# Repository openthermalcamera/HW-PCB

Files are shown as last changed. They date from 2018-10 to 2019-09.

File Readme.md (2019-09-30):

# Open Thermal Camera - KiCad PCB
This repository contains KiCad source files for Open Thermal Camera PCB.

The PCB is 2 layer, thickness of 0.8mm (To accommodate the edge TypeC / MicroUSB connector)

Under releases you can find:
- Interactive BOM (.html)
- KiCost BOM (.xlsx)
- Gerbers
- Position files (.pos & .rpt)  

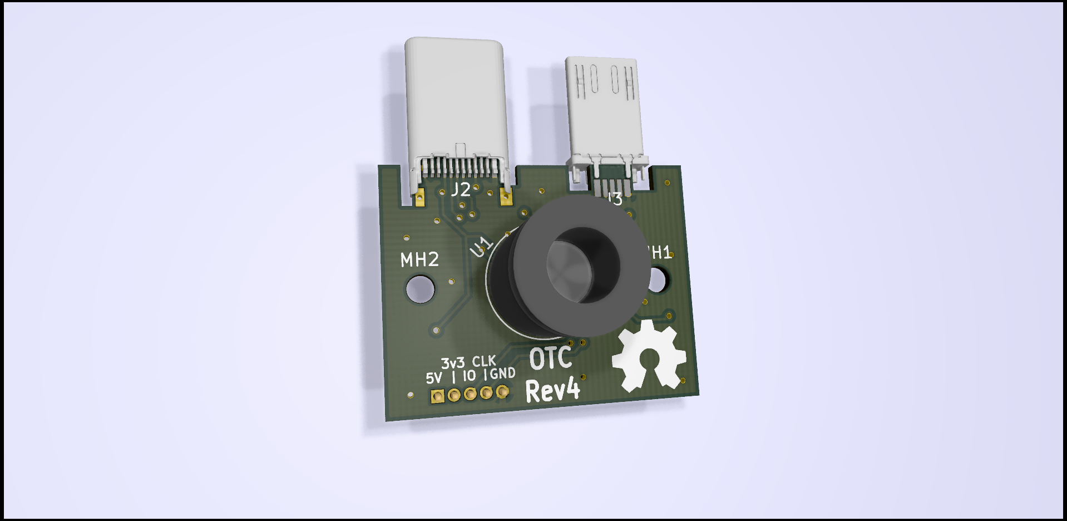
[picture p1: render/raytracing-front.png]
Raytracing render of rev4-fix1 PCB


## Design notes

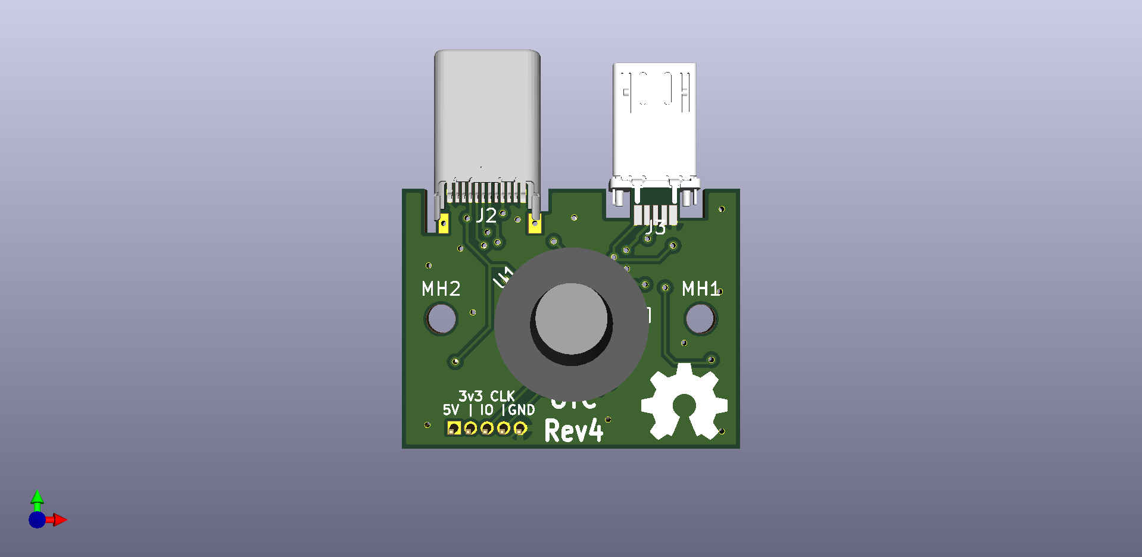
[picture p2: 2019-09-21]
render/render-front.png

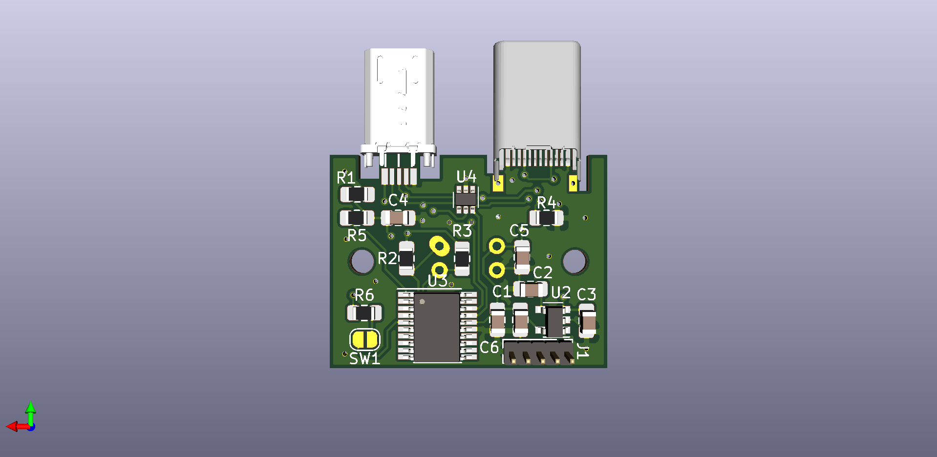
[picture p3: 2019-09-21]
render/render-back.png

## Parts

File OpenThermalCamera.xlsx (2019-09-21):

Prj: | OpenThermalCamera |  |  |  |  | Board Qty: | 1
Co.: | Martin Peterlin - TheMarpe |  |  |  |  | Unit Cost: | €45.13
Prj date: | 09/21/19 20:50:41 |  |  |  |  | Total Cost: | €45.13 |  |  |  | €47.81 | 13 of 13 parts found |  |  |  | €4.24 | 9 of 13 parts found |  |  |  | €46.12 | 13 of 13 parts found |  |  |  | €3.76 | 11 of 13 parts found |  |  |  | €311.62 | 7 of 13 parts found
$ date: | 2019-09-21 20:50:54
Global Part Info |  |  |  |  |  |  |  | Digi-Key |  |  |  |  | Farnell |  |  |  |  | Mouser |  |  |  |  | Newark |  |  |  |  | Rs Components
Refs | Value | Footprint | Manf | Manf# | Qty | Unit$ | Ext$ | Avail | Purch | Unit$ | Ext$ | Cat# | Avail | Purch | Unit$ | Ext$ | Cat# | Avail | Purch | Unit$ | Ext$ | Cat# | Avail | Purch | Unit$ | Ext$ | Cat# | Avail | Purch | Unit$ | Ext$ | Cat#
C1 | 2u2 | Capacitor_SMD:C_0805_2012Metric_Pad1.15x1.40mm_HandSolder |  | VJ0805G225KXYTW1BC | 1 | €0.16 | €0.16 | 3000 |  | €0.45 | €0.45 | 720-1727-1-ND (https://octopart.com/click/track?ai=8078&sig=0fba5b8&sid=459&ppid=46604723&vpid=464290379&ct=offers) | 11770 |  | €0.18 | €0.18 | 2896530 (https://octopart.com/click/track?ai=8078&sig=07624a5&sid=11744&ppid=46604723&vpid=494461261&ct=offers) | 1044 |  | €0.16 | €0.16 | 77VJ0805G225KXYTBC (https://octopart.com/click/track?ai=8078&sig=0643838&sid=2401&ppid=46604723&vpid=116520910&ct=offers) | 11770 |  | €0.16 | €0.16 | 62AC8496 (https://octopart.com/click/track?ai=8078&sig=0bba5bf&sid=2402&ppid=46604723&vpid=494777176&ct=offers)
C2 | 10n | Capacitor_SMD:C_0805_2012Metric_Pad1.15x1.40mm_HandSolder |  | 885012207011 | 1 | €0.04 | €0.04 | 5758 |  | €0.09 | €0.09 | 732-8021-1-ND (https://octopart.com/click/track?ai=8078&sig=05332f0&sid=459&ppid=65419785&vpid=229679422&ct=offers) | 6063 |  | €0.07 | €0.07 | 2534050 (https://octopart.com/click/track?ai=8078&sig=0bcfc16&sid=819&ppid=65419785&vpid=425232446&ct=offers) | 14171 |  | €0.09 | €0.09 | 710885012207011 (https://octopart.com/click/track?ai=8078&sig=01827dd&sid=2401&ppid=65419785&vpid=265812216&ct=offers) | 5283 |  | €0.09 | €0.09 | 15AC9380 (https://octopart.com/click/track?ai=8078&sig=091652a&sid=2402&ppid=65419785&vpid=423935271&ct=offers) | 3000 |  | €0.04 | €0.04 | 1814054 (https://octopart.com/click/track?c=1&ai=8078&sig=0fe3a41&sid=10022&ppid=65419785&vpid=527542116&ct=offers)
C3,C5,C6 | 100n | Capacitor_SMD:C_0805_2012Metric_Pad1.15x1.40mm_HandSolder |  | 0805B104K250CT | 3 | €0.02 | €0.05 | 598606 |  | €0.11 | €0.32 | 1292-1566-6-ND (https://octopart.com/click/track?ai=8078&sig=0d1fb69&sid=459&ppid=44502640&vpid=482068368&ct=offers) | 1000000 |  | €0.11 | €0.32 | 2496943 (https://octopart.com/click/track?ai=8078&sig=0ae86fd&sid=819&ppid=44502640&vpid=238084420&ct=offers) | 10790 |  | €0.09 | €0.27 | 7910805B104K250CT (https://octopart.com/click/track?ai=8078&sig=037a634&sid=2401&ppid=44502640&vpid=509504237&ct=offers) | 1000000 |  | €0.02 | €0.05 | 58Y7821 (https://octopart.com/click/track?ai=8078&sig=069d975&sid=2402&ppid=44502640&vpid=231885871&ct=offers) | NonStk |  | €0.02 | €0.05 | 1763302 (https://octopart.com/click/track?c=1&ai=8078&sig=0979f98&sid=10022&ppid=44502640&vpid=562996477&ct=offers)
C4 | 10uF | Capacitor_SMD:C_0805_2012Metric_Pad1.15x1.40mm_HandSolder |  | C2012X5R1C106K085AC | 1 | €0.04 | €0.04 | 1816187 |  | €0.21 | €0.21 | 445-7644-1-ND (https://octopart.com/click/track?ai=8078&sig=01e4528&sid=459&ppid=25947710&vpid=63973722&ct=offers) | 328000 |  | €0.20 | €0.20 | 2346924 (https://octopart.com/click/track?ai=8078&sig=0d12613&sid=11744&ppid=25947710&vpid=133117046&ct=offers) | 103997 |  | €0.21 | €0.21 | 810C2012X5R1C106K2 (https://octopart.com/click/track?ai=8078&sig=03961ac&sid=2401&ppid=25947710&vpid=66164356&ct=offers) | 3000 |  | €0.04 | €0.04 | 04X3273 (https://octopart.com/click/track?ai=8078&sig=0703545&sid=2402&ppid=25947710&vpid=88873678&ct=offers) | 57200 |  | €198.66 | €198.66 | 1110433 (https://octopart.com/click/track?c=1&ai=8078&sig=0bb9a74&sid=10022&ppid=25947710&vpid=271792902&ct=offers)
J2 | DX07P024AJ1R1500 | lib_fp:DX07P024AJ1R1500 | JAE Electronics | DX07P024AJ1R1500 | 1 | €1.53 | €1.53 | 1034 |  | €1.70 | €1.70 | 670-2868-1-ND (https://octopart.com/click/track?ai=8078&sig=084a4ed&sid=459&ppid=71471103&vpid=259292757&ct=offers) |  |  |  |  |  | 3446 |  | €1.53 | €1.53 | 656DX07P024AJ1R1500 (https://octopart.com/click/track?ai=8078&sig=0a7b5ed&sid=2401&ppid=71471103&vpid=255980038&ct=offers)
R1 | 50k | Resistor_SMD:R_0805_2012Metric_Pad1.15x1.40mm_HandSolder |  | CRCW080551K0JNEA | 1 | €0.001784280489 | €0.001784280489 | 61944 |  | €0.09 | €0.09 | 541-51KACT-ND (https://octopart.com/click/track?ai=8078&sig=0c2e4fe&sid=459&ppid=39789373&vpid=115968422&ct=offers) | 4656 |  | €0.01 | €0.01 | 1514873 (https://octopart.com/click/track?ai=8078&sig=0d7b924&sid=819&ppid=39789373&vpid=139776722&ct=offers) | 30756 |  | €0.09 | €0.09 | 71CRCW080551K0JNEA (https://octopart.com/click/track?ai=8078&sig=0732f5c&sid=2401&ppid=39789373&vpid=116516900&ct=offers) | 25000 |  | €0.001784280489 | €0.001784280489 | 59M6920 (https://octopart.com/click/track?ai=8078&sig=078ebd7&sid=2402&ppid=39789373&vpid=115417107&ct=offers)
R2,R3 | 4k7 | Resistor_SMD:R_0805_2012Metric_Pad1.15x1.40mm_HandSolder |  | CRCW08054K70FKEA | 2 | €0.03 | €0.06 | 71382 |  | €0.09 | €0.18 | 541-4.70KCCT-ND (https://octopart.com/click/track?ai=8078&sig=0d6806c&sid=459&ppid=39437405&vpid=114979004&ct=offers) | 580000 |  | €0.03 | €0.06 | 1469923 (https://octopart.com/click/track?ai=8078&sig=069b841&sid=819&ppid=39437405&vpid=249362388&ct=offers) | 52660 |  | €0.09 | €0.18 | 71CRCW08054.7KE3 (https://octopart.com/click/track?ai=8078&sig=06e54b9&sid=2401&ppid=39437405&vpid=114829042&ct=offers) | 65745 |  | €0.11 | €0.22 | 53K0215 (https://octopart.com/click/track?ai=8078&sig=039bd06&sid=2402&ppid=39437405&vpid=115417066&ct=offers) | 161400 |  | €54.88 | €109.77 | 1694716 (https://octopart.com/click/track?c=1&ai=8078&sig=0fc0c50&sid=10022&ppid=39437405&vpid=501389797&ct=offers)
R4 | 5k1 | Resistor_SMD:R_0805_2012Metric_Pad1.15x1.40mm_HandSolder |  | CRCW08055K10FKEAC | 1 | €0.01 | €0.01 | NonStk |  | €0.01 | €0.01 | CRCW08055K10FKEAC-ND (https://octopart.com/click/track?c=1&ai=8078&sig=0148ee9&sid=459&ppid=87885329&vpid=454322310&ct=offers) |  |  |  |  |  | 36179 |  | €0.12 | €0.12 | 71CRCW08055K10FKEAC (https://octopart.com/click/track?ai=8078&sig=08b7ec6&sid=2401&ppid=87885329&vpid=458954671&ct=offers) | 35000 |  | €0.01 | €0.01 | 95AC8936 (https://octopart.com/click/track?ai=8078&sig=0e65cdd&sid=2402&ppid=87885329&vpid=530876765&ct=offers)
R5,R6 | 1k | Resistor_SMD:R_0805_2012Metric_Pad1.15x1.40mm_HandSolder |  | CRCW08051K00FKEAC | 2 | €0.01 | €0.03 | 845546 |  | €0.09 | €0.18 | 541-3977-1-ND (https://octopart.com/click/track?ai=8078&sig=057cb21&sid=459&ppid=22248120&vpid=454353752&ct=offers) |  |  |  |  |  | 476302 |  | €0.09 | €0.18 | 71CRCW08051K00FKEAC (https://octopart.com/click/track?ai=8078&sig=0fc7168&sid=2401&ppid=22248120&vpid=455078622&ct=offers) | NonStk |  | €0.01 | €0.03 | 98AC1020 (https://octopart.com/click/track?c=1&ai=8078&sig=00c578c&sid=2402&ppid=22248120&vpid=532301100&ct=offers)
U1 | MLX90640 | lib_fp:MLX90640 | Melexis | MLX90640ESF-BAB-000-SP (http://datasheet.octopart.com/MLX90640ESF-BAB-000-SP-Melexis-datasheet-104525313.pdf) | 1 | €40.14 | €40.14 | 169 |  | €41.34 | €41.34 | MLX90640ESF-BAB-000-SP-ND (https://octopart.com/click/track?c=1&ai=8078&sig=00e2062&sid=459&ppid=91472901&vpid=477784722&ct=offers) |  |  |  |  |  | 163 |  | €40.14 | €40.14 | 482MLX90640ESFBABSP (https://octopart.com/click/track?ai=8078&sig=08a3e50&sid=2401&ppid=91472901&vpid=480476869&ct=offers)
U2 | TPS79333-EP | Package_TO_SOT_SMD:SOT-23-5 | Texas Instruments | TPS79333DBVR (http://www.ti.com/lit/ds/symlink/tps79333-ep.pdf) | 1 | €0.64 | €0.64 | 18300 |  | €0.67 | €0.67 | 296-12961-6-ND (https://octopart.com/click/track?ai=8078&sig=0295eef&sid=459&ppid=525272&vpid=34353681&ct=offers) | NonStk |  | €0.65 | €0.65 | 1470478 (https://octopart.com/click/track?c=1&ai=8078&sig=04ca578&sid=11744&ppid=525272&vpid=547751783&ct=offers) | 15320 |  | €0.64 | €0.64 | 595TPS79333DBVR (https://octopart.com/click/track?ai=8078&sig=0b4db10&sid=2401&ppid=525272&vpid=37722785&ct=offers) | 4234 |  | €0.64 | €0.64 | 77C1365 (https://octopart.com/click/track?ai=8078&sig=0fe0be9&sid=2402&ppid=525272&vpid=3030975&ct=offers) | 3460 |  | €0.66 | €0.66 | 6614490 (https://octopart.com/click/track?ai=8078&sig=0d9031f&sid=10022&ppid=525272&vpid=199171836&ct=offers)
U3 | STM32F042F6Px | Package_SO:TSSOP-20_4.4x6.5mm_P0.65mm | STMicroelectronics | STM32F042F6P6 (http://www.st.com/st-web-ui/static/active/en/resource/technical/document/datasheet/DM00105814.pdf) | 1 | €2.00 | €2.00 | 2214 |  | €2.01 | €2.01 | 497-17344-ND (https://octopart.com/click/track?ai=8078&sig=0336943&sid=459&ppid=34084830&vpid=438816131&ct=offers) | 22350 |  | €2.11 | €2.11 | 2469549 (https://octopart.com/click/track?ai=8078&sig=0e843bf&sid=819&ppid=34084830&vpid=209386396&ct=offers) | 6022 |  | €2.01 | €2.01 | 511STM32F042F6P6 (https://octopart.com/click/track?ai=8078&sig=0596617&sid=2401&ppid=34084830&vpid=183946111&ct=offers) | 22348 |  | €2.01 | €2.01 | 42Y1015 (https://octopart.com/click/track?ai=8078&sig=004a9a0&sid=2402&ppid=34084830&vpid=212750442&ct=offers) | 815 |  | €2.00 | €2.00 | 8607501 (https://octopart.com/click/track?ai=8078&sig=0d545e3&sid=10022&ppid=34084830&vpid=215021200&ct=offers)
U4 | NUP2202 | Package_TO_SOT_SMD:SOT-363_SC-70-6 | ON SEMICONDUCTOR | NUP2202W1T2G (http://www.onsemi.ru.com/pub_link/Collateral/NUP2202W1-D.PDF) | 1 | €0.44 | €0.44 | 41358 |  | €0.58 | €0.58 | NUP2202W1T2GOSDKR-ND (https://octopart.com/click/track?ai=8078&sig=09c37d5&sid=459&ppid=1390500&vpid=51297359&ct=offers) | 5494 |  | €0.63 | €0.63 | 2533276 (https://octopart.com/click/track?ai=8078&sig=02ae48e&sid=11744&ppid=1390500&vpid=259451652&ct=offers) | 12496 |  | €0.51 | €0.51 | 863NUP2202W1T2G (https://octopart.com/click/track?ai=8078&sig=0c8e1cb&sid=2401&ppid=1390500&vpid=37716427&ct=offers) | 5510 |  | €0.51 | €0.51 | 81Y7068 (https://octopart.com/click/track?ai=8078&sig=0a7f88b&sid=2402&ppid=1390500&vpid=260423814&ct=offers) | 9780 |  | €0.44 | €0.44 | 463690 (https://octopart.com/click/track?ai=8078&sig=0669eb6&sid=10022&ppid=1390500&vpid=199088847&ct=offers)
 | Used currency rates: |  |  |  |  | Total Purchase: | €0.00 |  |  |  | €0.00 |  |  |  |  | €0.00 |  |  |  |  | €0.00 |  |  |  |  | €0.00 |  |  |  |  | €0.00
 | EUR(€)/GBP(£): | 1.155468254
 | EUR(€)/USD($): | 0.8921402444
KiCost® v.1.1

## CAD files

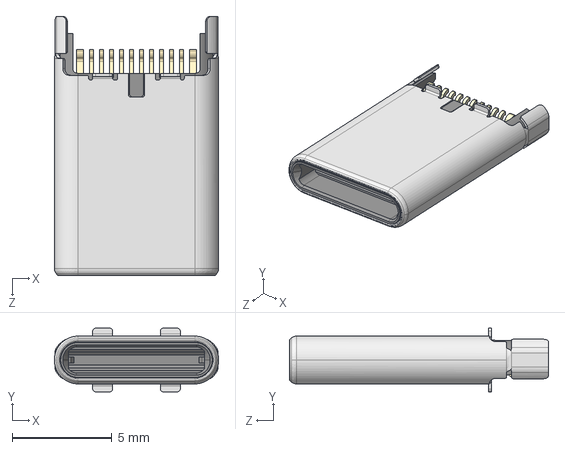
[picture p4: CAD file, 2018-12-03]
3d_models/DX07P024AJ1R1500--3DModel-STEP-56544.STEP
8.25 x 3.20 x 13.0 mm

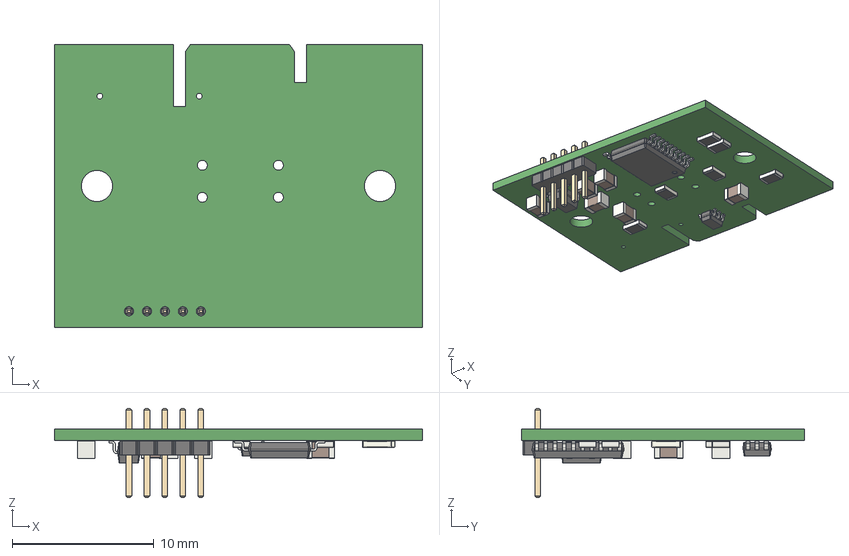
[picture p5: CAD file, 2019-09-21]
OpenThermalCamera.step
26.0 x 20.0 x 6.30 mm
micro5p_reversible_3d_crude
DX07P024AJ1R1500
mlx90640_3d

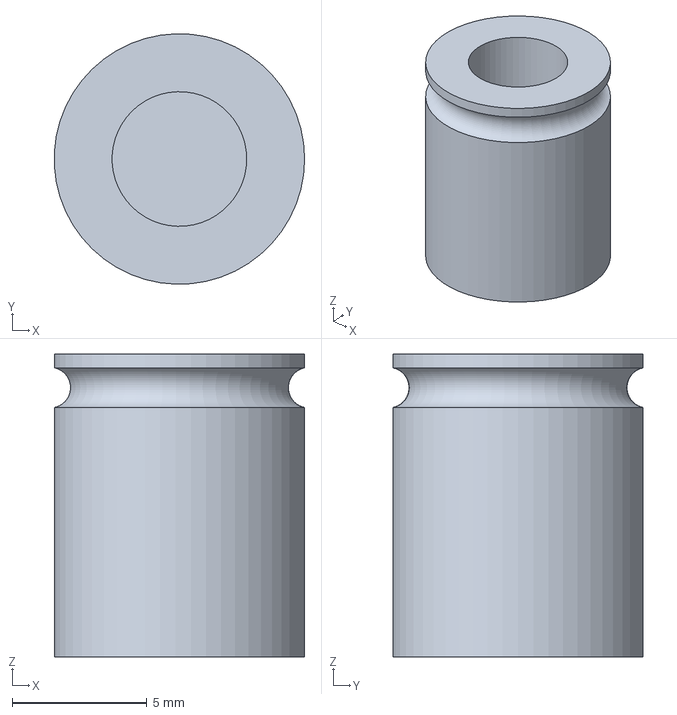
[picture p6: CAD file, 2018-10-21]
3d_models/mlx90640_3d.FCStd
9.29 x 9.30 x 11.2 mm

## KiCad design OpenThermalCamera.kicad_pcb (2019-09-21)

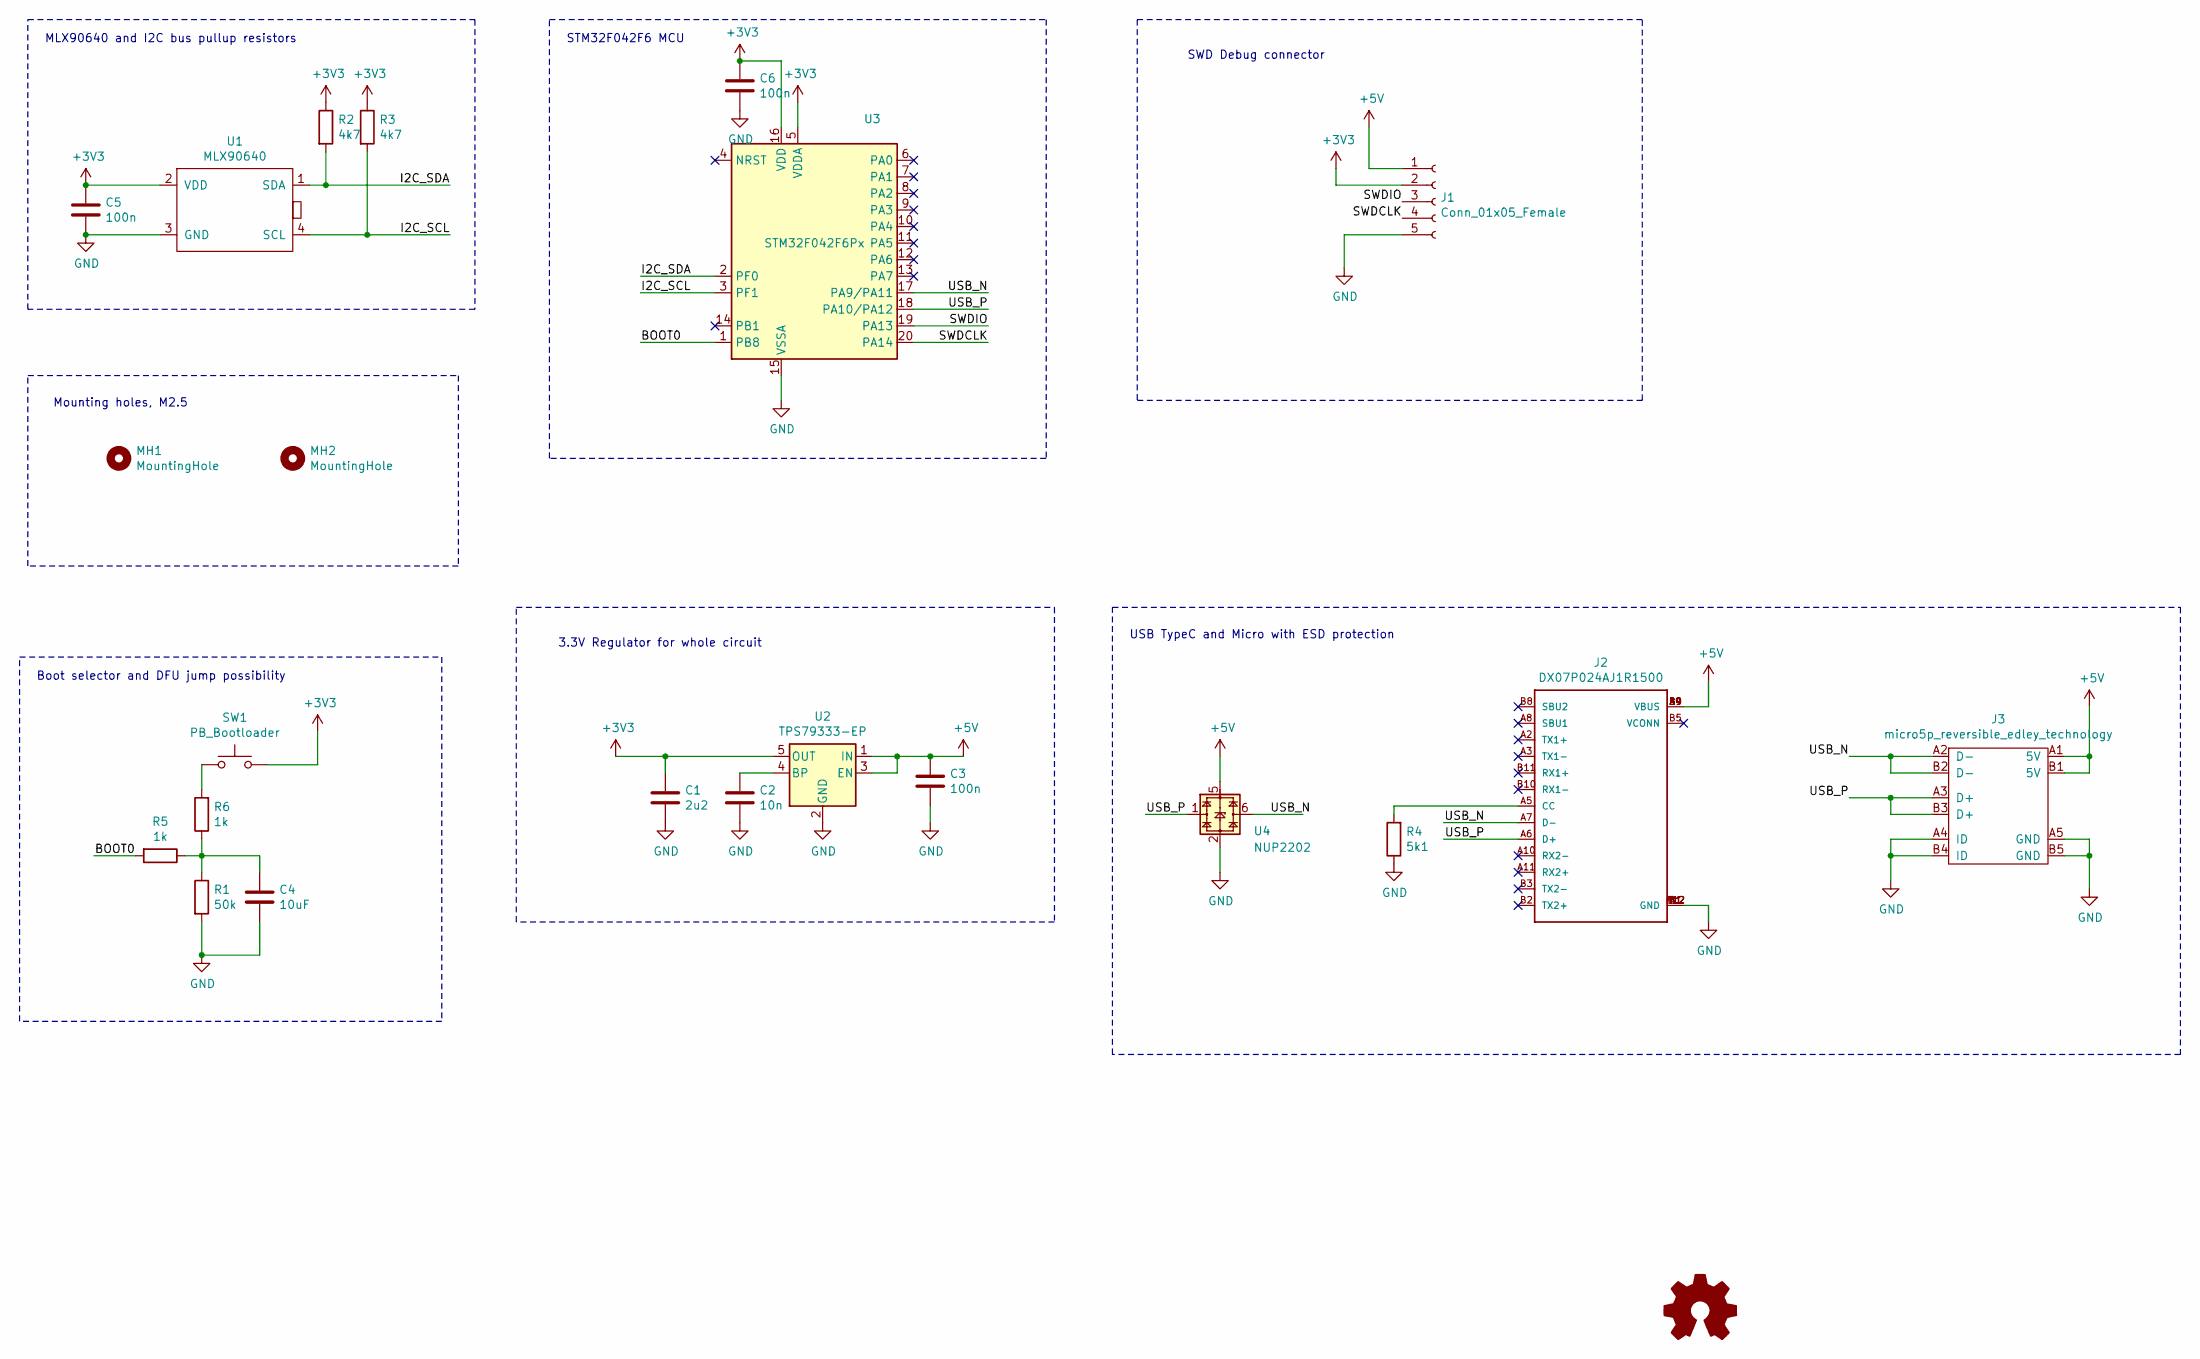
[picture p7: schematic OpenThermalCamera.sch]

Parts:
C1: 2u2; C_0805_2012Metric_Pad1.15x1.40mm_HandSolder; Part Number 2896530
C2: 10n; C_0805_2012Metric_Pad1.15x1.40mm_HandSolder; Part Number 2534050
C3, C6: 100n; C_0805_2012Metric_Pad1.15x1.40mm_HandSolder; Part Number 2496943
C4: 10uF; C_0805_2012Metric_Pad1.15x1.40mm_HandSolder; mfr# C2012X5R1C106K085AC
C5: 100n; C_0805_2012Metric_Pad1.15x1.40mm_HandSolder; mfr# 0805B104K250CT
G1: Logo_Open_Hardware_Small; OSHW-Logo2_7.3x6mm_SilkScreen
J1: Conn_01x05_Female; PinHeader_1x05_P1.27mm_Vertical
J2: DX07P024AJ1R1500; Part Number 656-DX07P024AJ1R1500
J3: micro5p_reversible_edley_technology; reversible_micro_usb
MH1, MH2: MountingHole; MountingHole_2.7mm_M2.5
R1: 50k; R_0805_2012Metric_Pad1.15x1.40mm_HandSolder; mfr# CRCW080551K0JNEA
R2, R3: 4k7; R_0805_2012Metric_Pad1.15x1.40mm_HandSolder; mfr# CRCW08054K70FKEA
R4: 5k1; R_0805_2012Metric_Pad1.15x1.40mm_HandSolder; mfr# CRCW08055K10FKEAC
R5, R6: 1k; R_0805_2012Metric_Pad1.15x1.40mm_HandSolder; mfr# CRCW08051K00FKEAC
SW1: PB_Bootloader; SolderJumper-2_P1.3mm_Open_RoundedPad1.0x1.5mm; Part Number /
U1: MLX90640; Part Number 482-MLX90640ESFBABSP
U2: TPS79333-EP; SOT-23-5; mfr# TPS79333DBVR
U3: STM32F042F6Px; TSSOP-20_4.4x6.5mm_P0.65mm; Part Number 511-STM32F042F6P6TR
U4: NUP2202; SOT-363_SC-70-6; Part Number 2533276

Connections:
+3V3: C1.1, C5.1, C6.1, J1.2, R2.1, R3.1, SW1.2, U1.2 (VDD), U2.5 (OUT), U3.5 (VDDA), U3.16 (VDD)
+5V: C3.1, J1.1, J2.A4 (VBUS), J2.A9 (VBUS), J2.B4 (VBUS), J2.B9 (VBUS), J3.A1 (5V), J3.B1 (5V), U2.1 (IN), U2.3 (EN), U4.5
/BOOT0: R5.2, U3.1 (PB8)
/I2C_SCL: R3.2, U1.4 (SCL), U3.3 (PF1)
/I2C_SDA: R2.2, U1.1 (SDA), U3.2 (PF0)
/SWDCLK: J1.4, U3.20 (PA14)
/SWDIO: J1.3, U3.19 (PA13)
/USB_N: J2.A7 (D-), J3.A2 (D-), J3.B2 (D-), U3.17 (PA9/PA11), U4.6
/USB_P: J2.A6 (D+), J3.A3 (D+), J3.B3 (D+), U3.18 (PA10/PA12), U4.1
GND: C1.2, C2.2, C3.2, C4.2, C5.2, C6.2, J1.5, J2.A1 (GND), J2.A12 (GND), J2.B1 (GND), J2.B12 (GND), J3.A4 (ID), J3.A5 (GND), J3.B4 (ID), J3.B5 (GND), R1.2, R4.1, U1.3 (GND), U2.2 (GND), U3.15 (VSSA), U4.2
unnamed: C2.1, U2.4 (BP)
unnamed: C4.1, R1.1, R5.1, R6.1
unnamed: J2.A5 (CC), R4.2
unnamed: R6.2, SW1.1

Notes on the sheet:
SWD Debug connector
USB TypeC and Micro with ESD protection
3.3V Regulator for whole circuit
MLX90640 and I2C bus pullup resistors
STM32F042F6 MCU
Boot selector and DFU jump possibility
Mounting holes, M2.5

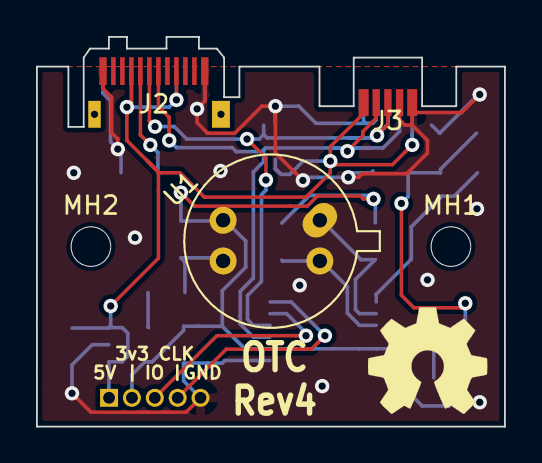
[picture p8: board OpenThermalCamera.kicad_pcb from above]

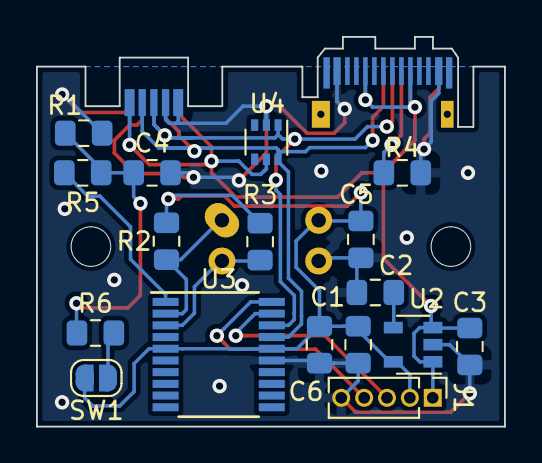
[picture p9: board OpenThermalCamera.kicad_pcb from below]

Board: 2 copper layers, 26.0 x 21.6 mm, 23 parts (17 on the bottom side), 14 nets.

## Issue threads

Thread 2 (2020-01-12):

Processor keeps dying

nlbutts, 2020-01-12:
I've gone through three processors. The first time I power the unit up it appears as a DFU unit. The first unit I built I was able to program your code on the unit and then it enumerated as another USB Uart. Although I couldn't get it to respond to PING or VERSION commands.

I then download the source, built it and tried to program the unit. Somehow it appears I've killed the unit. I remove the processor and placed a second, new one. That showed up as a DFU device. Although I could seem to program it. After messing with it for a while it would no longer show up as a DFU device.

I tried a third and had similar results. Even if I short the boot pins, I can't get it to show up as a DFU device. I've used many STM processors at work and have never seen one die like this.

Have you seen anything like this?

themarpe, 2020-01-13:
Occasionally I got them in a state where I couldn't get them to boot in the bootloader anymore. Using a debugger I was able to reflash it with appropriate firmware again. Never killed any of them, they turned out fine after the reflash.

Which board revision are you using?
Did you use the latest release files for the firmware?
How are you flashing the unit?

nlbutts, 2020-01-14:
I think I'm using the latest version of the PCB. I just ordered the board a few weeks ago and built it this last weekend.

I tried to JTAG, but RESET isn't connected, so I haven't had any luck JTAG the device. I have an ST-LINK/V2 that I tried. I also have a Segger. I'm going to try that next.

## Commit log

2018-12-11 Rev3: fixed MLX90640 footprint
    [OpenThermalCamera-B.Cu.gbr, OpenThermalCamera-B.Mask.gbr, OpenThermalCamera-B.SilkS.gbr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]
2018-12-12 Fixed USB Type-C edge cuts
    [OpenThermalCamera.kicad_pcb]
2019-02-19 Added solder mask on MLX sensor pads
    [OpenThermalCamera.kicad_pcb]
2019-03-01 Preperations for Rev3
    [OpenThermalCamera-B.Cu.gbr, OpenThermalCamera-B.Mask.gbr, OpenThermalCamera-B.SilkS.gbr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]
2019-03-01 First Rev3-C commit
    [OpenThermalCamera-B.Cu.gbr, OpenThermalCamera-B.Mask.gbr, OpenThermalCamera-B.SilkS.gbr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]
2019-09-21 Fixed reversible microusb footprint
    [FarnellShopCart_5boards.csv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]
2019-09-30 Added additional PCB information
